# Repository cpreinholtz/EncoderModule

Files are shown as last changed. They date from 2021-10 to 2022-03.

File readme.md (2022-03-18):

# Overview - Dorthy - Digital Rotary Encoder based Teensy Synth
This repo contains several PCB designs and teensy firmware for building a digital sythesiser.

**Directory structure:**
* cad (empty...)
* doc (mostly datasheets and links to research sources)
* firmware (arduino sketches)
* hardware (eagle projects)
* production (gerber zips)
* simulation (empty...)

**PCBs (see detailed descriptions below)**
* **R**otary **E**ncoder **E**xpander **M**odule (REEM)
* **G**round **I**solated **M**idi **I**nput Module (GIMI)
* **D**igital **R**otary Encoder **T**eensy S**y**nth (DRTY / DORTHY)

## Rotary Encoder Expander Module (REEM)

### Overview

This module is meant to be an expandable way to attach many rotary encoders to a single i2c master.  The idea is that it can be used in creating a nice user interface for a synthesizer.  This project is meant to be small, to keep manufacturing costs down, but also expandable so that multiple of these can be connected together to make a large io pannel. Currently limited to 8 modules or 64 knobs based on the io expander chip used.

### Hardare Features

* Voltage input 1.8 — 5.5 V
* Optional pullups on SCL and SDA, do not pupulate by default,  should be pulled up on master side.
* Chainable design, simply connect modules using the ribbon cable connectors. (VCC, GND, SCL, SDA).
* 3 address pins per chip allow up to 8 unique addresses.  
 * **The address pins are floating by default and must be tied to vcc or ground by shorting one of the two 0805 resitor pads per pin**

### Future Considerations
* If you want chainable interupts, its probably possible, especially with more io lines on the chips
* it may be nice to someday take advantage of the switches built into the encoders, but i thought i would skip for now
* Optional hardware filter circuits for each encoder might improve performance but would mean more soldering
* Instead of an encoder, We could allow switches or buttons in the same form factor.
* Consider a form factor that fits with eurorack standards.
 * The Eurorack format calls for modules of 128.5mm (slightly over 5") height. Horizontal width is measured in "horizontal pitch", where 1 HP = 5.08mm (exactly 0.2").  This is larger than eagle free can build and fab houses may charge more 
* I wonder if it would be cheaper to use JST connectors for board to board connections.  See adafruit Trellis for example.

## **G**round **I**solated **M**idi **I**nput Module (GIMI)

### 

### Overview
Classic octocoupler used for midi digitization for arduino or similar controllers.

***Warning ***
In rev 1 of producing this baord the M4 and M5 pin labels were swapped on the silkscreen.  Refer to the schematic and drawings, not the silkscreen.

### Hardare Features
* reverse polarity protection diode.
* midi in uses octocoupler preventing ground loops.  
* RX pullup does not need to be 5v.  Can be tied to 3v3, or whatever voltage the controller needs.
* Jumper for quickly disconnecting RX from the circuit.  For re-programming certain controllers Rx may need to be floating.

### Future Considerations
* It would be pretty easy to add midi through and/or midi out at some point.
* It may be nice to get board mount midi connectors at some point.
* It may be nice to start using a standard cable (like JST SH or JST PH...) rather than the 100mil pitch headers I put on.

## Dorthy Teensy Synth (work in progress)
Designed around a teensy microcontroller and some other hardware modules.  Utilizes the teensy audio libraries and some custom firmware.

### Playing the Synth
Instructions and features tbd.

## Dorthy Teensy Synth Hardare 
Take a teensy, slap 64 knobs and 16 buttons onto it, make it midi compatable and make some music

#### BOM
* 1x Teensy microcontroller, at least Rev 3.5 reccomended.
* 1x Midi in GIMI module (hardware/midi_in)
* 8x REEM modules(hardware/MultiEncoder)
* 2x large capacitors for stereo audio out, simple bypass cap to bring it to 0v centered.
* LCD display? tbd
* trellis? https://www.adafruit.com/product/3954

#### Hardware Pinouts
TBD

## Dorthy Teensy Synth Firmware
This synth will make heavy use of the teensy audio libraries and other goodies found all over the web.  Special thanks to all the contributors!

#### Firmware Detailed Descriptions (Requirments...)
* Polled processes: knobs(>100Hz), capacitive touch pads(100Hz?), midi RX(Every loop), Trellis (100Hz?), Clock Monitor(Every Loop), Touchscreen(100Hz?)
* While polling, if something is found that requires updates, the dispatcher class is called.
* When called the dispatcher will perform one or more actions such as modifying the voices or other synth parameters, and updating the display.
* The synth itself will have N voices, each with its own oscilators, LFOs?, amplitude envelope, filter and filter envelope.
* The synth will then combine all voices and send them through an effects signal chain containing delay, reverb, bitcrush, etc.
* The synth will respond to pitch bending and modwheel messages.
* The synth will be able to store up to M "note on" messages at a time, and will use the LAST N notes on the voices, upon notoffs it will go back through the list in revers chronological order.

#### Firmware Immediate Todo List
* Test what happens if the SetScalers function is passed a max smaler than min, hopefully it just reverses the knob polarity, that would be sweet
* Rewrite Midi function so that it does not take 50 ms to exxecute...
* Figure out why polyphonic note off does not often continue the release envelope if another note is hit.

#### Firmware Future Considerations
* It would be nice to have a good sequencer in the future, (keep this in mind when writing the dispatcher and voice controls)  consider things like kbd play / stack live 
* It would be nice to have a built in drum machine in the future.
* It would be nice to have the ability to save patches.  (make settings easy to get / set)
* It would be nice to be able to swap LFOs from incremental clk sync to continuous bpm sweeps.  this requires some back and forth from dispatcher to clk and lfo.
* It would be nice to be able to swap from re-triggering envelopes on each additional key to using one envelop for all voices(more smooth /legatto)

#### Firmware Enviromental setup
All you should need is arduino IDE with the teensy 3.6 board installed.
Teensy 1.53 seems to work much faster than the latest versions, Note to self: I have a copy of the 1.53 installer on my google drive main folder "installexes.rar" 
Arduino 1.8.13 works with this version of Teensy, I think I had issues with 1.8.16 and that teensy version.

#### Firmware Dependencies
TBD

#### Firmware Limitations
TBD

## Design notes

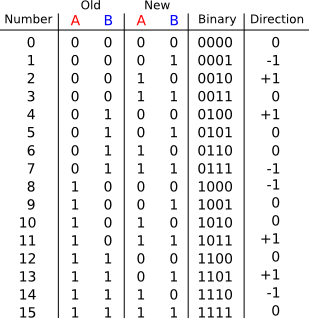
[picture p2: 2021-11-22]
doc/quadrature_table.png

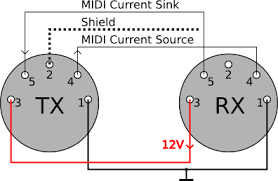
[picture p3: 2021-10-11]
doc/download.png

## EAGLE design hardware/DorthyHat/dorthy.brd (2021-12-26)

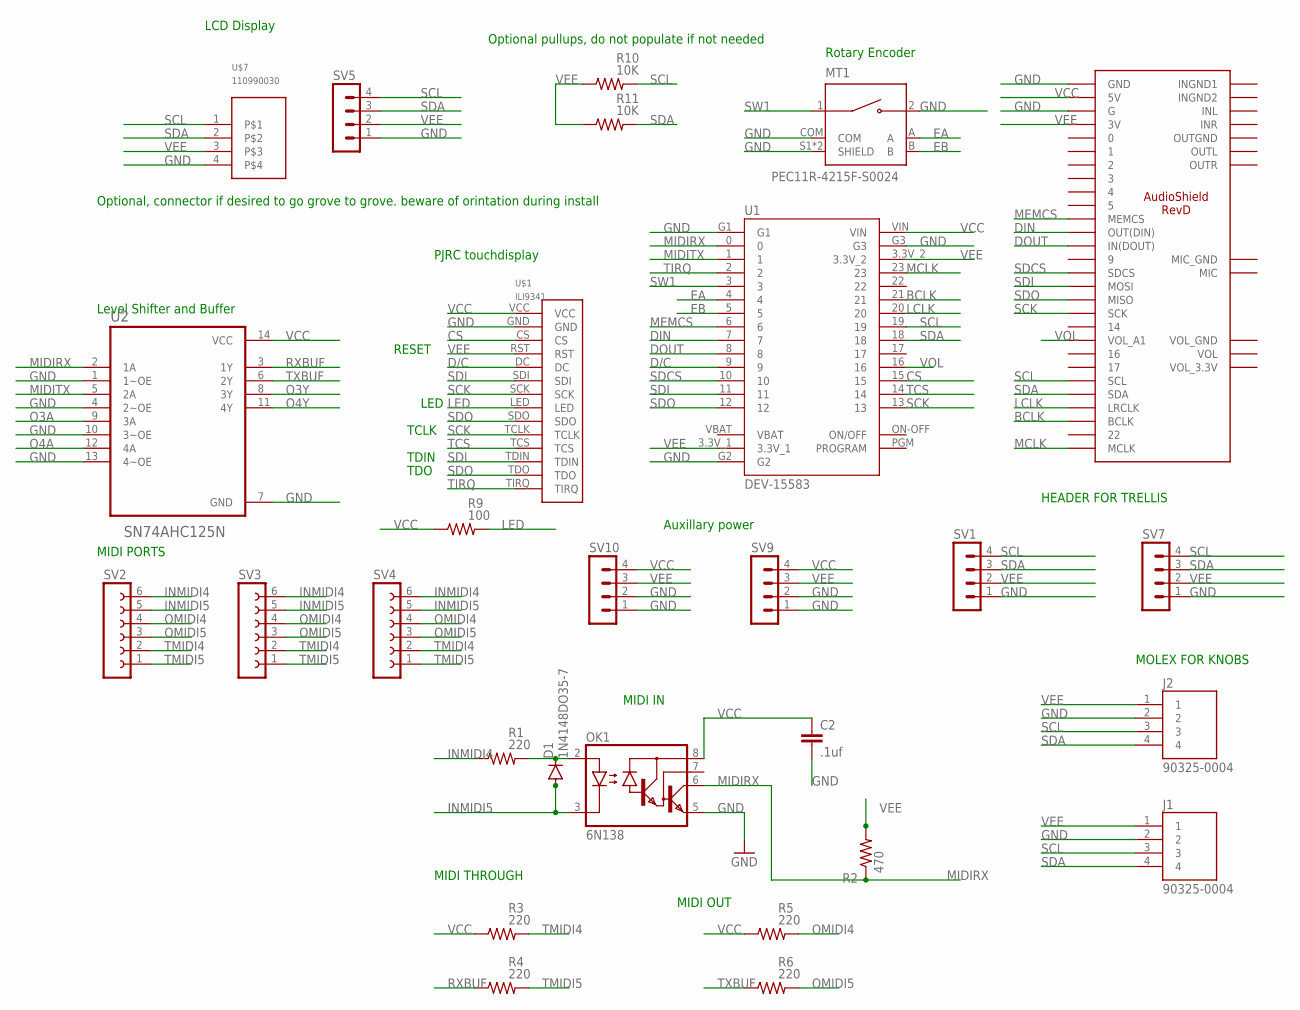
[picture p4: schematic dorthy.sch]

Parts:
C2: .1uf; C5B3.5
D1: 1N4148DO35-7; DO35-7
J1, J2: 90325-0004; MOLEX_90325-0004
MT1: PEC11R-4215F-S0024; XDCR_PEC11R-4215F-S0024
OK1: 6N138; DIL08
R1, R3, R4, R5, R6: 220; 0207/10
R2: 470; 0207/10
R9: 100; 0207/10
R10, R11: 10K; 0207/10
SV1, SV5, SV7, SV9, SV10: MA04-1
SV2, SV3, SV4: FE06-1; FE06
U1: DEV-15583; MODULE_DEV-15583
U2: SN74AHC125N; DIP794W45P254L1969H508Q14
U$1: ILI9341
U$2: AUDIOSHIELD-REVD
U$7: 110990030; 110990030-VERTICAL-GROVE-CONNECTOR

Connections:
BCLK: U1.21, U$2.21 (BCLK)
CS: U1.15, U$1.CS
D/C: U1.9, U$1.DC
DIN: U1.7, U$2.7 (OUT(DIN))
DOUT: U1.8, U$2.8 (IN(DOUT))
EA: MT1.A, U1.4
EB: MT1.B, U1.5
GND: C2.2, J1.2, J2.2, MT1.2, MT1.COM, MT1.S1 (SHIELD), MT1.S2 (SHIELD), OK1.5 (GND), SV1.1, SV5.1, SV7.1, SV9.1, SV9.2, SV10.1, SV10.2, U1.G1, U1.G2, U1.G3, U2.1 (1~OE), U2.4 (2~OE), U2.7 (GND), U2.10 (3~OE), U2.13 (4~OE), U$1.GND, U$2.G, U$2.GND, U$7.4
INMIDI4: R1.1, SV2.6, SV3.6, SV4.6
INMIDI5: D1.A, OK1.3 (C), SV2.5, SV3.5, SV4.5
LCLK: U1.20, U$2.20 (LRCLK)
LED: R9.2, U$1.LED
MCLK: U1.23, U$2.23 (MCLK)
MEMCS: U1.6, U$2.6 (MEMCS)
MIDIRX: OK1.6 (VO), R2.1, U1.0, U2.2 (1A)
MIDITX: U1.1, U2.5 (2A)
unnamed: D1.C, OK1.2 (A), R1.2
O3A: U2.9 (3A)
O3Y: U2.8 (3Y)
O4A: U2.12 (4A)
O4Y: U2.11 (4Y)
OMIDI4: R5.2, SV2.4, SV3.4, SV4.4
OMIDI5: R6.2, SV2.3, SV3.3, SV4.3
RXBUF: R4.1, U2.3 (1Y)
SCK: U1.13, U$1.SCK, U$1.TCLK, U$2.13 (SCK)
SCL: J1.3, J2.3, R10.2, SV1.4, SV5.4, SV7.4, U1.19, U$2.19 (SCL), U$7.1
SDA: J1.4, J2.4, R11.2, SV1.3, SV5.3, SV7.3, U1.18, U$2.18 (SDA), U$7.2
SDCS: U1.10, U$2.10 (SDCS)
SDI: U1.11, U$1.SDI, U$1.TDIN, U$2.11 (MOSI)
SDO: U1.12, U$1.SDO, U$1.TDO, U$2.12 (MISO)
SW1: MT1.1, U1.3
TCS: U1.14, U$1.TCS
TIRQ: U1.2, U$1.TIRQ
TMIDI4: R3.2, SV2.2, SV3.2, SV4.2
TMIDI5: R4.2, SV2.1, SV3.1, SV4.1
TXBUF: R6.1, U2.6 (2Y)
VBAT: U1.VBAT
VCC: C2.1, OK1.8 (VCC), R3.1, R5.1, R9.1, SV9.4, SV10.4, U1.VIN, U2.14 (VCC), U$1.VCC, U$2.5V
VEE: J1.1, J2.1, R2.2, R10.1, R11.1, SV1.2, SV5.2, SV7.2, SV9.3, SV10.3, U1.3.3V_1, U1.3.3V_2, U$1.RST, U$2.3V, U$7.3
VOL: U1.16, U$2.15 (VOL_A1)

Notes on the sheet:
Optional pullups, do not populate if not needed
MIDI THROUGH
MIDI OUT
MIDI IN
MOLEX FOR KNOBS
HEADER FOR TRELLIS
MIDI PORTS
Level Shifter and Buffer
PJRC touchdisplay
LED
RESET
TCLK
TDIN
TDO
Rotary Encoder
Auxillary power
LCD Display
Optional, connector if desired to go grove to grove. beware of orintation during install

Board: 2 copper layers, 28 parts (0 on the bottom side), 35 nets, no tracks yet.

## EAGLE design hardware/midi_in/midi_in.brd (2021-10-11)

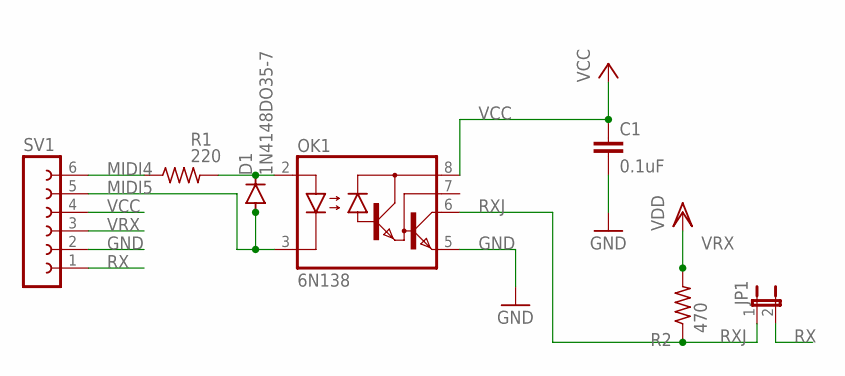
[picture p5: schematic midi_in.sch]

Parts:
C1: 0.1uF; C10B5
D1: 1N4148DO35-7; DO35-7
JP1: JP1E; JP1
OK1: 6N138; DIL08
R1: 220; 0207/10
R2: 470; 0207/10
SV1: FE06-1; FE06

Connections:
GND: C1.2, OK1.5 (GND), SV1.2
MIDI4: R1.1, SV1.6
MIDI5: D1.A, OK1.3 (C), SV1.5
unnamed: D1.C, OK1.2 (A), R1.2
RX: JP1.2, SV1.1
RXJ: JP1.1, OK1.6 (VO), R2.1
VCC: C1.1, OK1.8 (VCC), SV1.4
VRX: R2.2, SV1.3

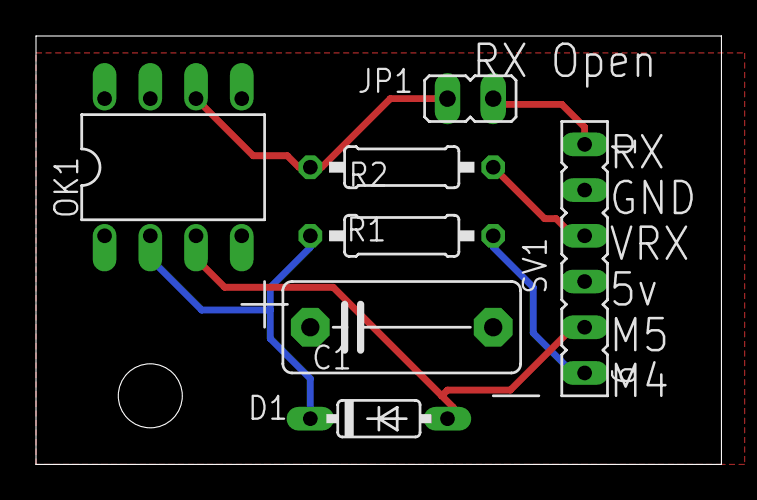
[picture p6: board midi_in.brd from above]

Board: 2 copper layers, 38.1 x 23.8 mm, 7 parts (0 on the bottom side), 8 nets.

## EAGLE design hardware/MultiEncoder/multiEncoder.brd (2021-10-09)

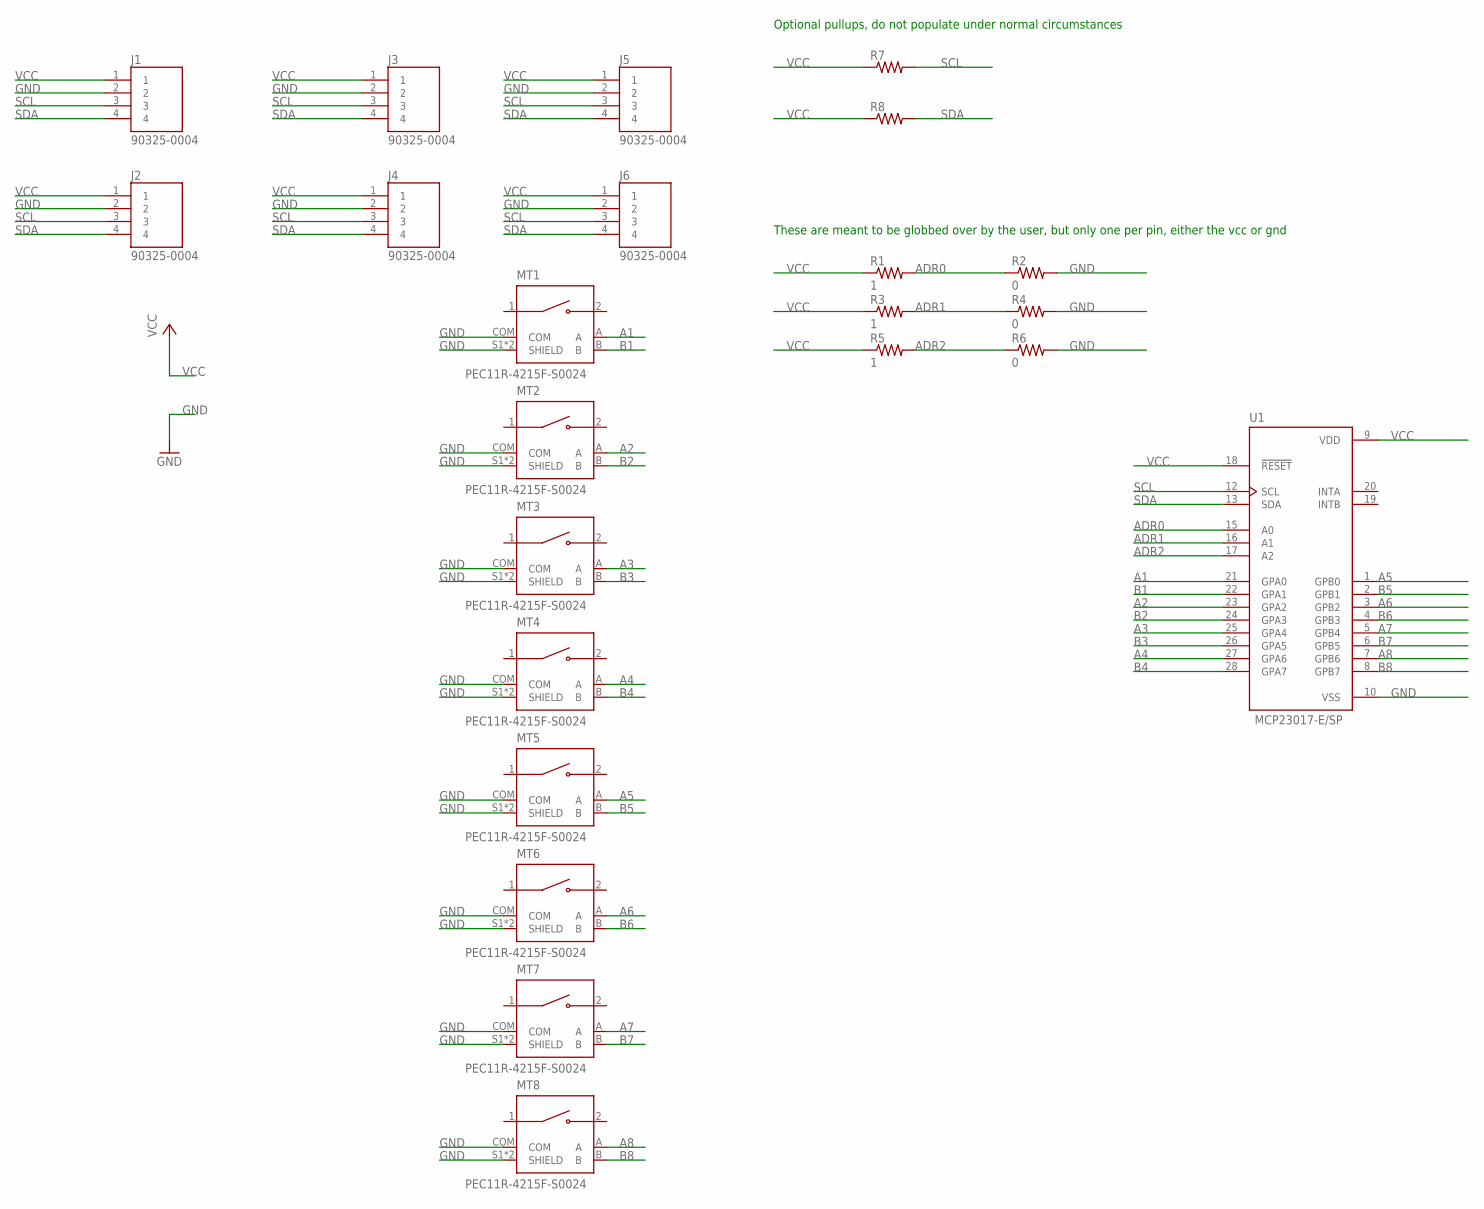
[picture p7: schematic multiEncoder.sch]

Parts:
J1, J2, J3, J4, J5, J6: 90325-0004; MOLEX_90325-0004
MT1, MT2, MT3, MT4, MT5, MT6, MT7, MT8: PEC11R-4215F-S0024; XDCR_PEC11R-4215F-S0024
R1, R3, R5: 1; R0805
R2, R4, R6: 0; R0805
R7, R8: 1K; R0805
U1: MCP23017-E/SP; DIP787W45P254L3556H508Q28

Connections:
A1: MT1.A, U1.21 (GPA0)
A2: MT2.A, U1.23 (GPA2)
A3: MT3.A, U1.25 (GPA4)
A4: MT4.A, U1.27 (GPA6)
A5: MT5.A, U1.1 (GPB0)
A6: MT6.A, U1.3 (GPB2)
A7: MT7.A, U1.5 (GPB4)
A8: MT8.A, U1.7 (GPB6)
ADR0: R1.2, R2.1, U1.15 (A0)
ADR1: R3.2, R4.1, U1.16 (A1)
ADR2: R5.2, R6.1, U1.17 (A2)
B1: MT1.B, U1.22 (GPA1)
B2: MT2.B, U1.24 (GPA3)
B3: MT3.B, U1.26 (GPA5)
B4: MT4.B, U1.28 (GPA7)
B5: MT5.B, U1.2 (GPB1)
B6: MT6.B, U1.4 (GPB3)
B7: MT7.B, U1.6 (GPB5)
B8: MT8.B, U1.8 (GPB7)
GND: J1.2, J2.2, J3.2, J4.2, J5.2, J6.2, MT1.COM, MT1.S1 (SHIELD), MT1.S2 (SHIELD), MT2.COM, MT2.S1 (SHIELD), MT2.S2 (SHIELD), MT3.COM, MT3.S1 (SHIELD), MT3.S2 (SHIELD), MT4.COM, MT4.S1 (SHIELD), MT4.S2 (SHIELD), MT5.COM, MT5.S1 (SHIELD), MT5.S2 (SHIELD), MT6.COM, MT6.S1 (SHIELD), MT6.S2 (SHIELD), MT7.COM, MT7.S1 (SHIELD), MT7.S2 (SHIELD), MT8.COM, MT8.S1 (SHIELD), MT8.S2 (SHIELD), R2.2, R4.2, R6.2, U1.10 (VSS)
SCL: J1.3, J2.3, J3.3, J4.3, J5.3, J6.3, R7.2, U1.12 (SCL)
SDA: J1.4, J2.4, J3.4, J4.4, J5.4, J6.4, R8.2, U1.13 (SDA)
VCC: J1.1, J2.1, J3.1, J4.1, J5.1, J6.1, R1.1, R3.1, R5.1, R7.1, R8.1, U1.9 (VDD), U1.18 (!RESET)

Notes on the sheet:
These are meant to be globbed over by the user, but only one per pin, either the vcc or gnd
Optional pullups, do not populate under normal circumstances

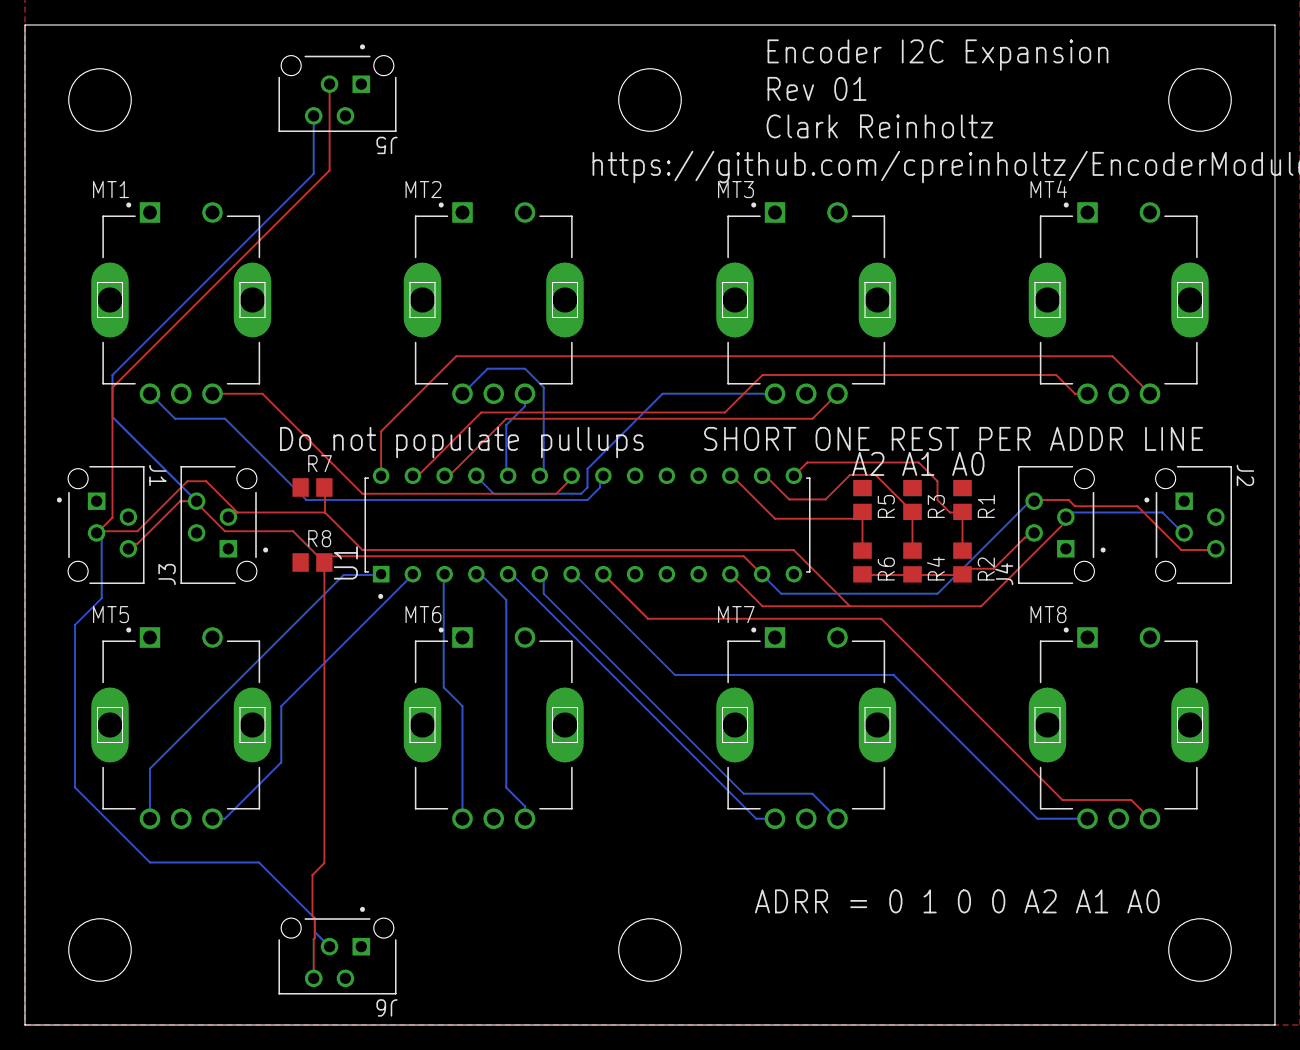
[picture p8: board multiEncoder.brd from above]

Board: 2 copper layers, 100.0 x 80.0 mm, 23 parts (0 on the bottom side), 23 nets.

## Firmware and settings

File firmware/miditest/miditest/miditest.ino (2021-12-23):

#include <Audio.h>
#include <Wire.h>
#include <SPI.h>
#include <SD.h>
#include <SerialFlash.h>

#include <MIDI.h>
#include "notes.h"
#include "voices.h"




Voices gVoices;
Notes gNotes;
//Timer knobTimer(1000);

Timer knobTimer(5000);
//GreyCounter gc;

// Simple midi test, based off the "simpleSynth" example for the teensy   Note, your midi keyborad needs to be transmitting on channel 4!
MIDI_CREATE_DEFAULT_INSTANCE();


// -----------------------------------------------------------------------------

void setup()
{
    AudioMemory(600);
    //pinMode(sGatePin,     OUTPUT);
    //pinMode(sAudioOutPin, OUTPUT);

    //https://github.com/FortySevenEffects/arduino_midi_library/wiki/Using-Callbacks
    MIDI.setHandleNoteOn(handleNoteOn);
    MIDI.setHandleNoteOff(handleNoteOff);    
    MIDI.setHandleControlChange(handleControlChange);
    MIDI.setHandlePitchBend(handlePitchBend);
    
    MIDI.begin(4); //channel
    Serial.begin(115200);
    Serial.println("here");
    

    
    initAudio();
    initControl();
    initMcp();


    
}



void loop()
{ 

    MIDI.read();

    if (knobTimer.pollAndReset()){
        getKnobs();
    }
}

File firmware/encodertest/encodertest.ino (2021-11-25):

//encoder test based on this resource:
// http://makeatronics.blogspot.com/2013/02/efficiently-reading-quadrature-with.html


#include "grey_counter.h"
#include "time.h"



const int gA= 3;
const int gB= 4;
GreyCounter gc;

Timer knobTimer(100);


void setup() {
    // all your normal setup code

    pinMode(gA,INPUT_PULLUP);
    pinMode(gB,INPUT_PULLUP);
    

    Serial.begin(9600);
    Serial.println("here");



    //gc.initCounter( (digitalRead(gA)<<1)  | digitalRead(gB) );
    gc.initCounter( digitalRead(gA), digitalRead(gB) );

}





void loop()
{


    if (knobTimer.pollAndReset()){
        //GreyState gs = gc.updateCounter(digitalRead(gA), digitalRead(gB));    
        gc.updateCounter( (digitalRead(gA)<<1)  | digitalRead(gB) );
    
        
        if (gc.getChanged()){
            Serial.println(gc.getCount());
        }       
    }
    

    
}

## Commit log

2021-10-08 inital commit
    [multiEncoder.brd, multiEncoder.sch]
2021-10-08 change to 8 knob per module, 64 knob max
    [multiEncoder.brd, multiEncoder.sch]
2021-10-08 Parts are placed, add ploygons and optional i2c line pullups
    [multiEncoder.brd, multiEncoder.sch]
2021-10-08 run autorouter on all signals beddides addr lines
    [multiEncoder.brd]
2021-10-08 All signals routed, ERC and DRC passes, just need to check footprints really
    [multiEncoder.brd, multiEncoder.sch]
2021-10-09 Switch to a dip package for the ioexpander chip, re route signals
    [multiEncoder.brd, multiEncoder.sch]
2021-10-09 fix an unrouted net
    [multiEncoder.brd]
2021-10-09 add vertical connection option
    [multiEncoder.brd, multiEncoder.sch]
2021-10-09 Add identifying markings to silkscreen
    [multiEncoder.brd]
2021-10-09 Add gerber zipfile
2021-10-09 move addr1 line away from addr0 pad, regenerate gerbers
    [multiEncoder.brd]
2021-10-09 add midi input module
    [midi_in.brd, midi_in.sch]
2021-10-11 swap M4 and M5 silkscreen for midi in. Big doccumentation update
    [midi_in.brd]
2021-11-19 add initial schematic for the 'Dorthy' teensy sheild
    [dorthy.brd, dorthy.sch]
2021-11-20 added touch screen lcd to dorthy, realized teensy 4.0 does not have true analog outputs, need to revert to 3.5 if I want simple outs...
    [dorthy.brd, dorthy.sch]
2021-11-20 change to teensy 3.6. Add AGND for audio outs. Add power headers for future addons
    [dorthy.brd, dorthy.sch]
2021-11-20 make board 100mmX100mm. add 9 capacitive touch pads. add rotary encoder... why not?
    [dorthy.brd, dorthy.sch]
2021-11-21 add midi test sketch. The teensy + GIMI module are working with 5 pin midi in!
2021-11-22 add object oriented implimentation of encoder motion tracking with the hope that is is easly expandable to multiple knobs in the future
2021-11-24 teensy wont boot
2021-11-27 knob polling works with up to 7 reems, 8 seems to be too much capacitance, todo, make logrithmic scaling for lfo bpm
    [control_dispach.ino, mcp.ino, miditest.ino]
2021-11-27 Added effect signal chain!
2021-11-28 remove frequency LFO, trim signal before filter to minimize clipping, increase filter resonance limits, change a few other scalers
2021-12-23 use aduiosheild rather than built in DAc output. increase knob polling frequency to every 5 ms, runs well on teensy 4.0
2021-12-24 change shematic (back) to teensy 4.0, with audio sheild and touch display
    [dorthy.brd, dorthy.sch]
2021-12-24 add custom footprint for the display
    [dorthy.brd, dorthy.sch]
2021-12-24 start moving components around
    [dorthy.brd]
2021-12-25 Component placement first pass finished for Dorthy
    [dorthy.brd, dorthy.sch]
2021-12-25 add holes and polygons
    [dorthy.brd]
2021-12-26 change triangle to square wave, volume to 1.0 on output
    [dorthy.brd]
2022-03-18 readme arduino version 1.8.13
